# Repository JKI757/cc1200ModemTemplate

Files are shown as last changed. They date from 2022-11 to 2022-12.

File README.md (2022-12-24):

Very basic layout, based loosely on TI's EMK board, with component LCSC numbers cribbed from the M17 project's "Exploded M17" project.  matching network should be loosely around 440 mhz but you'll want to customize for your application.

I'm not an RF engineer or PCB layout expert, so use at your own risk.  Pull requests welcome if you know better than I do on anything here.  

License is unlicense, use it how you want to, I don't consider this to be intellectual property, it's just a combination of parts following datasheets and sample layouts.

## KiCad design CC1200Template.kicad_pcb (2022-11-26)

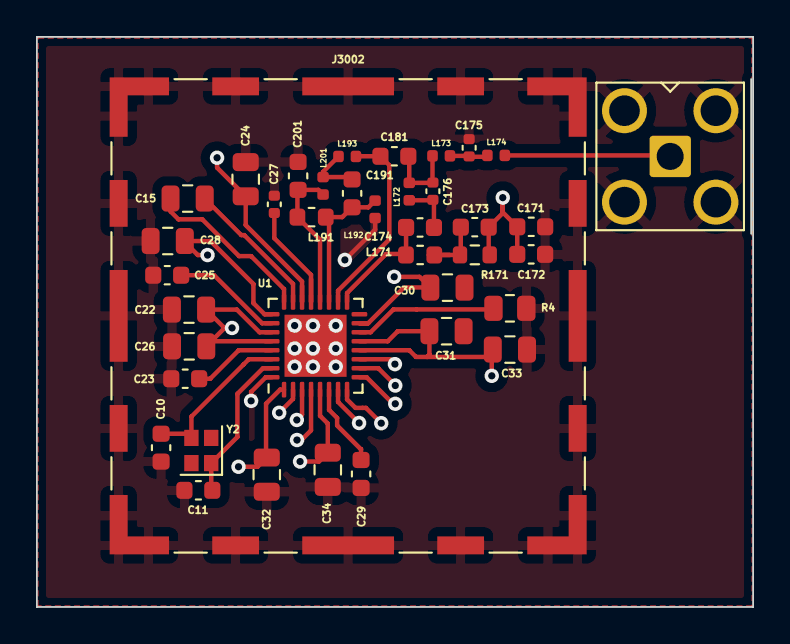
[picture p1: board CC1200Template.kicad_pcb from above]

Board: 4 copper layers, 39.8 x 31.7 mm, 39 parts (0 on the bottom side), 21 nets.

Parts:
C10, C11: 12p; C_0603_1608Metric
C15: 1.5n; C_0805_2012Metric
C22, C24, C26, C28, C30, C31, C32, C33, C34: 47n; C_0805_2012Metric
C23, C25: 47n; C_0603_1608Metric
C27: 10n; C_0402_1005Metric
C29: 220n; C_0603_1608Metric
C171: 10n; C_0603_1608Metric
C172: 100p; C_0603_1608Metric
C173: 56p; C_0603_1608Metric
C174: 39p; C_0603_1608Metric
C175: 6.2p; C_0402_1005Metric
C176: 2.2p; C_0402_1005Metric
C181, C191, C201: 5.1p; C_0603_1608Metric
J1: Conn_Coaxial; HJ_Tech_SMA_Horizontal_Board_Edge_RF
J3002: RFShield_OnePiece; Wuerth_36103255_25x25mm
L171, L191: 56n; L_0603_1608Metric
L172, L193: 15n; L_0402_1005Metric
L173: 43n; L_0402_1005Metric
L174: 22n; L_0402_1005Metric
L192, L201: 27n; L_0402_1005Metric
R4: 56k; R_0805_2012Metric
R171: 18; R_0603_1608Metric
U1: CC1200; QFN-32-1EP_5x5mm_P0.5mm_EP3.45x3.45mm
Y2: 40 MHz; Crystal_SMD_2016-4Pin_2.0x1.6mm

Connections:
+3V3: C22.1, C24.1, C26.1, C28.1, C30.1, C31.1, C32.1, C33.1, C34.1, C171.1, C172.1, C173.1, R171.1, U1.1 (VDD_GUARD), U1.5 (DVDD), U1.12 (DVDD), U1.13 (AVDD_IF), U1.15 (AVDD_RF), U1.22 (AVDD_SYNTH1), U1.25 (AVDD_PFD_CHP), U1.27 (AVDD_SYNTH2), U1.28 (AVDD_XOSC)
GND: C10.1, C11.2, C22.2, C23.2, C24.2, C25.2, C26.2, C27.2, C28.2, C29.2, C30.2, C31.2, C32.2, C33.2, C34.2, C171.2, C172.2, C175.2, C201.2, J1.2 (Ext), J3002.1 (Shield), L192.1, R4.2, U1.32 (EXT_XOSC), U1.33 (GND_EP)
unnamed: C10.2, U1.30 (XOSC_Q1), Y2.3
unnamed: C11.1, U1.31 (XOSC_Q2), Y2.1
unnamed: C15.1, U1.23 (LPF0)
unnamed: C15.2, U1.24 (LPF1)
unnamed: C23.1, U1.29 (DCPL_XOSC)
unnamed: C25.1, U1.26 (DCPL_PFD_CHP)
unnamed: C27.1, U1.21 (DCPL_VCO)
unnamed: C29.1, U1.6 (DCPL)
unnamed: C173.2, L171.2, R171.2
unnamed: C174.1, C176.2, L172.1
unnamed: C175.1, L173.2, L174.1
unnamed: C176.1, C181.1, L172.2, L173.1
unnamed: C181.2, L193.2, U1.18 (TRX_SW)
unnamed: C191.1, L191.1, L192.2, U1.19 (LNA_P)
unnamed: C191.2, L193.1, L201.1
unnamed: C201.1, L191.2, L201.2, U1.20 (LNA_N)
unnamed: J1.1 (In), L174.2
unnamed: R4.1, U1.14 (RBIAS)
unnamed: C174.2, L171.1, U1.17 (PA)

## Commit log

2022-11-25 fix clearance issues & errors in footprints
    [CC1200Template.kicad_pcb]
2022-11-26 fix clearance issues & errors in footprints and add vias for ground and add ground and vcc pours
    [CC1200Template.kicad_pcb, CC1200Template.kicad_sch]
